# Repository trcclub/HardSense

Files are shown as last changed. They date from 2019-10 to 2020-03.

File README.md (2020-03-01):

# HardSense
Monitor local system sensors and display that data on a remote 2.8" LCD screen.
Full touch screen enabled.
Multiple screens including GPU details, CPU details

https://youtu.be/yXnQ3QwIAQI

The hardware monitoring is provided by the Open Hardware Monitor library:  https://github.com/openhardwaremonitor/openhardwaremonitor

NOTE:
To buld HardSenseESP, you need to change the partition scheme.

HardSenseESP Tools configuration settings:
	Board:  "ESP32 Dev Module"
	Partition Scheme: "HardSense ESP Partition"

In Arduino IDE, these are under the 'Tools' menu item.
In vMicro (Visual Micro for Visual Studio), they are under 'vMicro' menu item.

Essential bits: 
Bodmers TFT_ESPI:  https://github.com/Bodmer/TFT_eSPI

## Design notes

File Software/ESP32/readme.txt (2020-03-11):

AddItemToDisplayQueue(DisplayCommands::UpdateValue, String <payload>);
payload = "<key>,<value>"

Value (when needed) must be at least 3 characters long.
This means to have an empty value, you must use a space.
examples:
AddItemToDisplayQueue(DisplayCommands::UpdateValue, String ("a, "));
AddItemToDisplayQueue(DisplayCommands::UpdateValue, String ("a,12.3"));
AddItemToDisplayQueue(DisplayCommands::UpdateValue, String ("a,Hello"));

These will fail:
AddItemToDisplayQueue(DisplayCommands::UpdateValue, String ("a,"));
AddItemToDisplayQueue(DisplayCommands::UpdateValue, String ("a"));

Custom Partition for HardSenseESP

Default direcectory for existing partisions is:
(Windows):
C:\Users\<USERID>\AppData\Local\Arduino15\packages\esp32\hardware\esp32\1.0.4\tools\partitions

New partion file is called:
hardsense_esp_partition.csv

'hardsense_esp_partition.csv' is based on the file 'min_spiffs.csv' which can be found
in the default partitions directory.  This file is a good starting point when creating
a custom project. 

The file 'boards.txt' is also important:
C:\Users\<USERID>\AppData\Local\Arduino15\packages\esp32\hardware\esp32\1.0.4\boads.txt

esp32.menu.PartitionScheme.hardsenseESP=HardSense ESP Partition (1.9MB APP with OTA/190KB SPIFFS)
esp32.menu.PartitionScheme.hardsenseESP.build.partitions=hardsense_esp_partition
esp32.menu.PartitionScheme.hardsenseESP.upload.maximum_size=1966080

Copy the file 'hardsense_esp_partition.csv' to your partitions directory.
Add the 3 'esp32.menu.' lines above to your boards.txt file.
Restart arduino.
Select 'HardSense ESP Partition' from the tools or board config  menus.

Reference links:
https://robotzero.one/arduino-ide-partitions/
https://lastminuteengineers.com/esp32-ota-updates-arduino-ide/

Sketch uses 1511122 bytes (76%) of program storage space. Maximum is 1966080 bytes.

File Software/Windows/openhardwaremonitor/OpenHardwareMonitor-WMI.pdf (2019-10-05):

Page 1
The Open Hardware Monitor WMI Provider | Protected under copyright, Release 1 - 2010-10-18

# Open Hardware Monitor

### 1 Preface and document conventions

This documented is intended for those who wish to utilise the information exposed to WMI by the Open Hardware Monitor. Its intentions are to provide some basic understanding of some of the structures used, mainly those which are relatively obscure.

### 2 Type definitions

### 2.1 HardwareType

public enum HardwareType { Mainboard,
SuperIO,
CPU,
GpuNvidia,
GpuAti,
TBalancer,
Heatmaster,
HDD,
}

HardwareType is an enumeration intended to distinguish various piece of hardware from each other. One cannot rely on a specific type to indicate the presence of specific sensors, if any at all. This is merely an indication of hardware type in order to be able to potentially use different styles based upon the hardware type. The individual values will not be detailed in this matter, because the names themselves are very clear, and as said, hold no further meaning.

Page 2

### 2.2 SensorType

public enum SensorType {
Voltage,
Clock,
Temperature,
Load,
Fan,
Flow,
Control,
Level
}

SensorType is an enumeration to distinguish between various sensors. From a sensor’s type, one should derive which display format is to be used, as each type of sensor has a logical unit attached.

Sensor Type | Unit used | Recommended display format
Voltage | Volt | «value» V
Clock | Megahertz | «value» MHz
Temperature | Celsius | «value» °C
Load | Percentage | «value»%
Fan | Revolutions per minute | «value» RPM
Flow | Liters per hour | «value» L/h
Control | Percentage | «value»%
Level | Percentage | «value»%

A few of these types require extra attention, as they are intended to be used under very specific circumstances.

The Load, Control, and Level types each use percentages as their unit, but have distinctly different purposes.

- Load: Represents the load on a piece of hardware, where 100% represents a fully loaded component.
- Control: Typically used in conjunction with fan controllers, used to represent the duty cycle.
- Level: This is a generic % based level measure, used when the above both don’t apply.

The flow type is currently only used in conjunction with the Alphacool Heatmaster (http://www.alphacool.com/product_info.php/info/p674_Alphacool-Heatmaster.html) and mCubed’s T-Balancer bigNG. (http://www.t-balancer.com/english/bng.htm) These two fan controllers have flow sensors for those who have liquid cooled systems and wish to monitor the volumetric flow rate through the system.

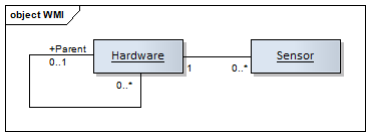
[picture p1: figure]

Page 3

### 3 The WMI provider

### 3.1 Basics

The Open Hardware Monitor publishes two distinct WMI classes, as detailed below. The namespace they are published to is called “root/OpenHardwareMonitor”. The cardinality between the 2 classes is defined as follows:

That is: Each sensor instance has exactly one matching parent hardware instance, but a hardware instance does not necessarily have any sensor instances attached to it.

Hardware may have a maximum of one matching parent hardware instance, but a hardware instance does not necessarily have any subhardware instances.

### 3.2 Hardware

Value type | Name | Description | Example
string | Name | Typically a combination of make and model | Intel Core 2 Duo E8400
string | Identifier | A unique identifier for this piece of hardware | /intelcpu/0
string | HardwareType | The HardwareType as defined in chapter 2.1 | CPU
string | Parent | The identifier of its parent Hardware; if any. | “/mainboard” or “”

The identifier includes a zero-based index in order to distinguish between identical pieces of hardware in a single system. This is common in multi-CPU and multi-GPU setups.

The parent identifier will be an empty string if there is no parent (as there won’t be for /mainboard for example).

The identifiers are unique per instance, but do not guarantee that the underlying hardware is 100% identical to a previous session. Taking the example of the Intel CPU above, a user could exchange this Intel Core 2 Duo E8400 for an Intel Core 2 Quad Q6600. The identifier will still be /intelcpu/0, but the underlying hardware has changed dramatically. Identifiers intend to identify a specific type of hardware, not the make and model. One has to take this into consideration when working with them, in order to avoid unexpected behaviour.

Page 4

### 3.3 Sensor

Value type | Name | Description | Example
string | Name | Typically relative to its parent | CPU Core #2
string | Identifier | A unique identifier for this Sensor | /intelcpu/0/load/1
string | SensorType | The SensorType as defined in chapter 2.2 | Load
string | Parent | The identifier of its parent Hardware | /intelcpu/0
float | Value | Last read value | 50
float | Min | Lowest read value | 0
float | Max | Highest read value | 100
int | Index | Index within the array of sensors of the same type | 1

The identifier includes a zero-based index in order to distinguish between similar sensors associated with a single piece of hardware. This is common in multi-core CPUs for examples, where each core can have its own Load or Temperature sensor.

The identifiers are unique per instance, but do not guarantee that the underlying hardware is 100% identical to a previous session. Taking the example of the Intel CPU above, a user could exchange this Intel Core 2 Duo E8400 for an Intel Core 2 Quad Q6600. The underlying hardware has changed dramatically, but where there were only 2 Load sensors before, there now are 4. Identifiers intend to identify a specific type of hardware, not the make and model. One has to take this into consideration when working with them, in order to avoid unexpected behaviour.

One has to take extra care with the Min, Max and Value properties. These are all of the float type, and as such will have to be parsed by the client before one can use them for calculations. One also has to take the unit associated with the SensorType into consideration.

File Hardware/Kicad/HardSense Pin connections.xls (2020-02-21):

TFT_Display |  | ESP32S | RTC | ESP32S
Touch | T_IRQ | N/A | DS | N/A
 | T_OUT | D19 | SCL | D22
 | T_IN | D23 | SDA | D21
 | T_CS | D15 | VCC | 3.3 v
 | T_CLK | D18 | GND | Gnd
TFT | MISO | D19
 | LED | 3.3v | Encoder | ESP32S
 | SCK | D18 | CLK | D35
 | MOSI | D23 | DT | D34
 | D/C | D4 | SW | N/A
 | Reset | D2 | + | 3.3 v
 | CS | D5 | GND | Gnd
 | GND | Gnd
 | VCC | 3/3 v | Button | ESP32S
 |  |  | Pin 1 | GND
 |  |  | Pin 2 | D13

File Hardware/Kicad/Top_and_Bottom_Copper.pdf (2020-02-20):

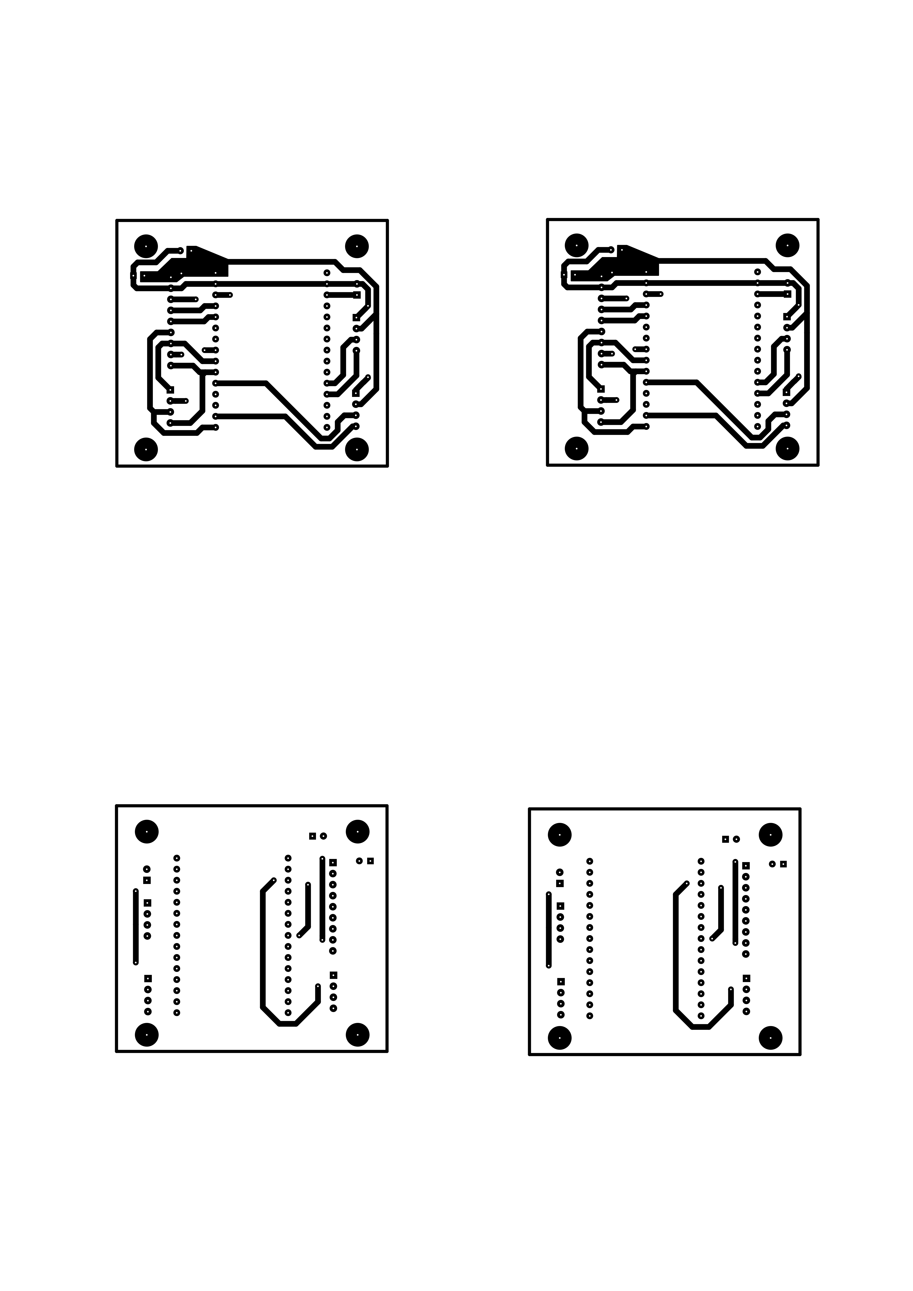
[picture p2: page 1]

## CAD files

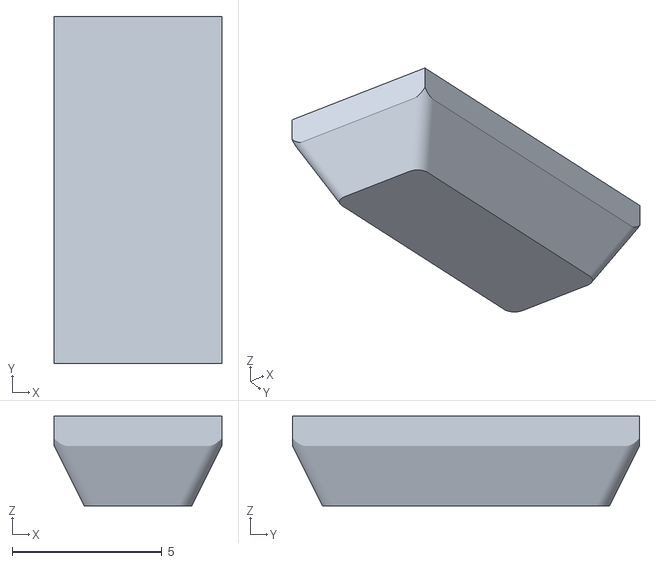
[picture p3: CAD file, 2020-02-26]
Hardware/STL Files/Foot Pad.stl
5.60 x 11.6 x 3.00

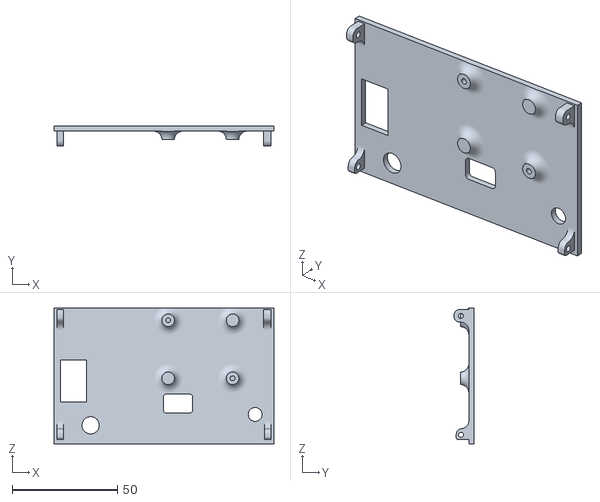
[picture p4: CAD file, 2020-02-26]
Hardware/STL Files/Back Plate.stl
104.6 x 9.40 x 64.5

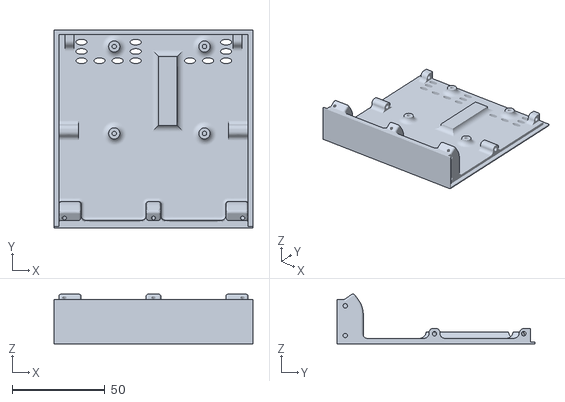
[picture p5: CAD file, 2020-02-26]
Hardware/STL Files/Base.stl
107.0 x 106.6 x 26.8

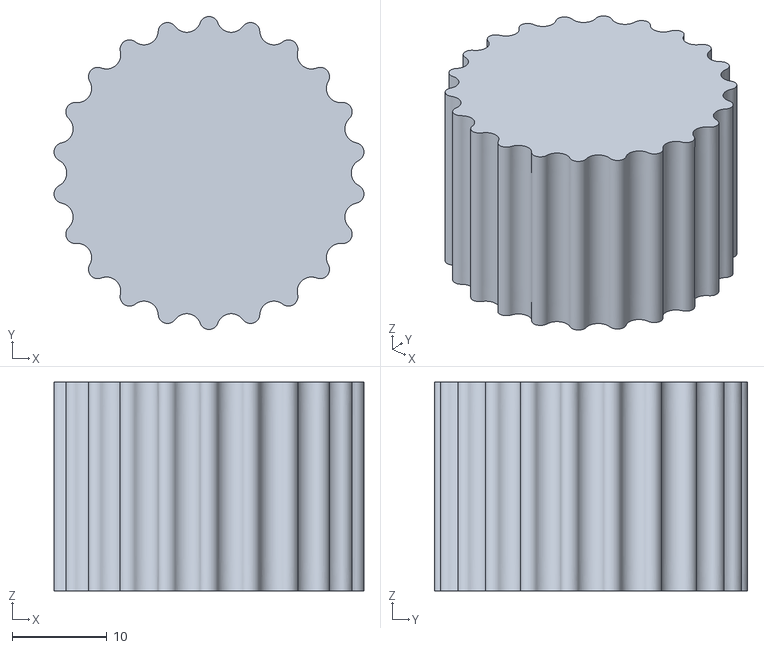
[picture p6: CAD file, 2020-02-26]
Hardware/STL Files/Metric Barrell.stl
32.7 x 33.0 x 22.0

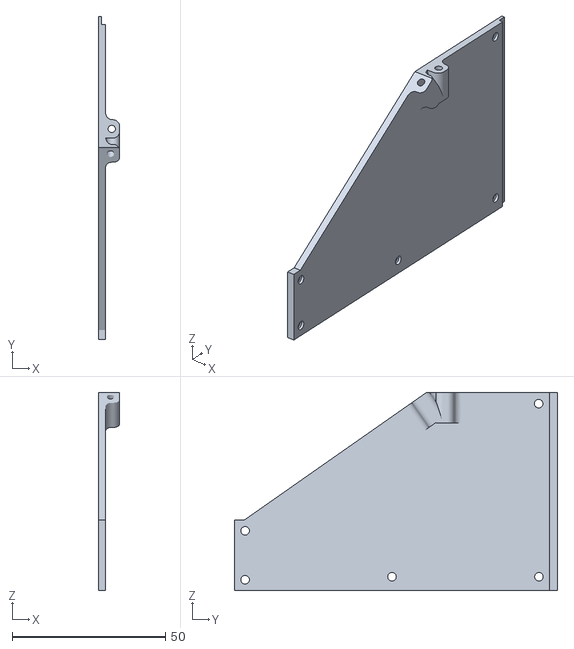
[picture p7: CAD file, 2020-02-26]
Hardware/STL Files/Left Side Panel.stl
7.00 x 105.6 x 64.7

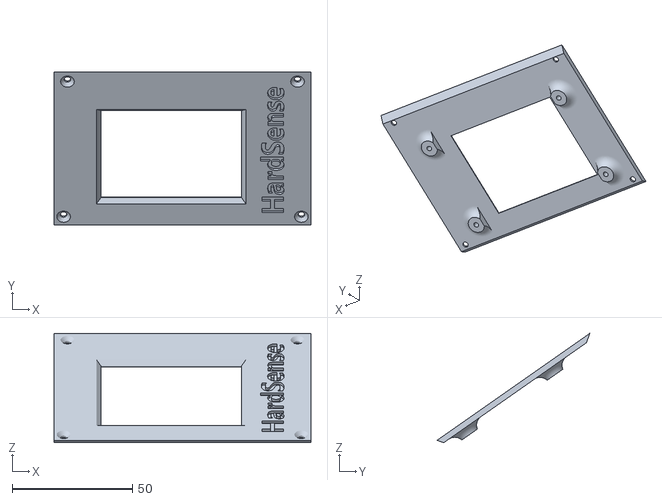
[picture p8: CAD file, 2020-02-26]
Hardware/STL Files/Display Panel.stl
107.0 x 63.6 x 45.6

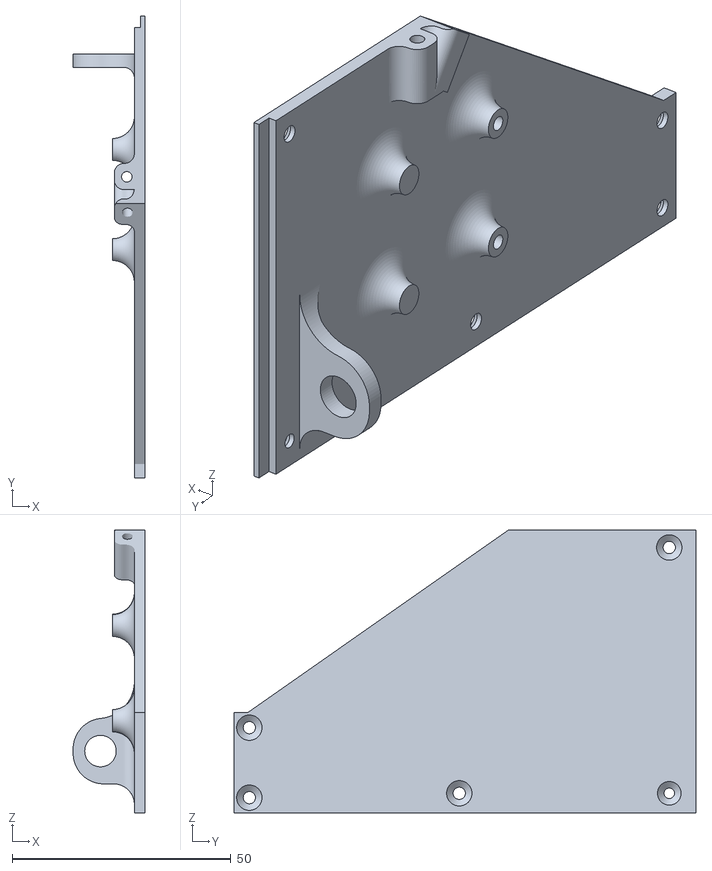
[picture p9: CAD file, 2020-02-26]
Hardware/STL Files/Right Side Panel.stl
16.4 x 105.6 x 64.7

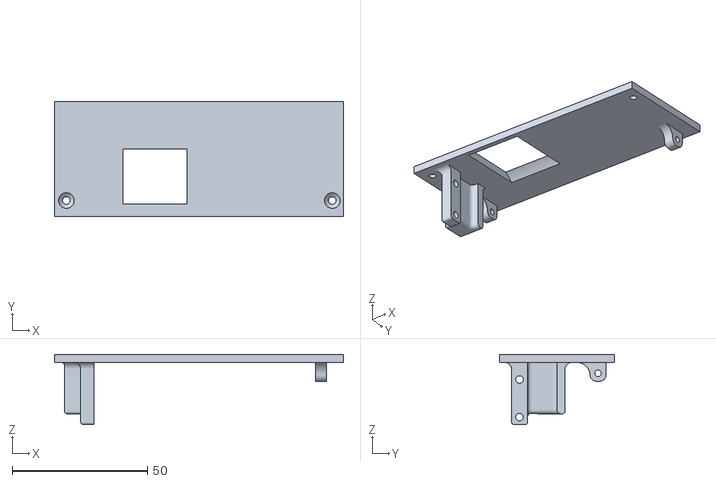
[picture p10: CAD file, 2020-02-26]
Hardware/STL Files/Top Plate.stl
107.0 x 42.8 x 26.0

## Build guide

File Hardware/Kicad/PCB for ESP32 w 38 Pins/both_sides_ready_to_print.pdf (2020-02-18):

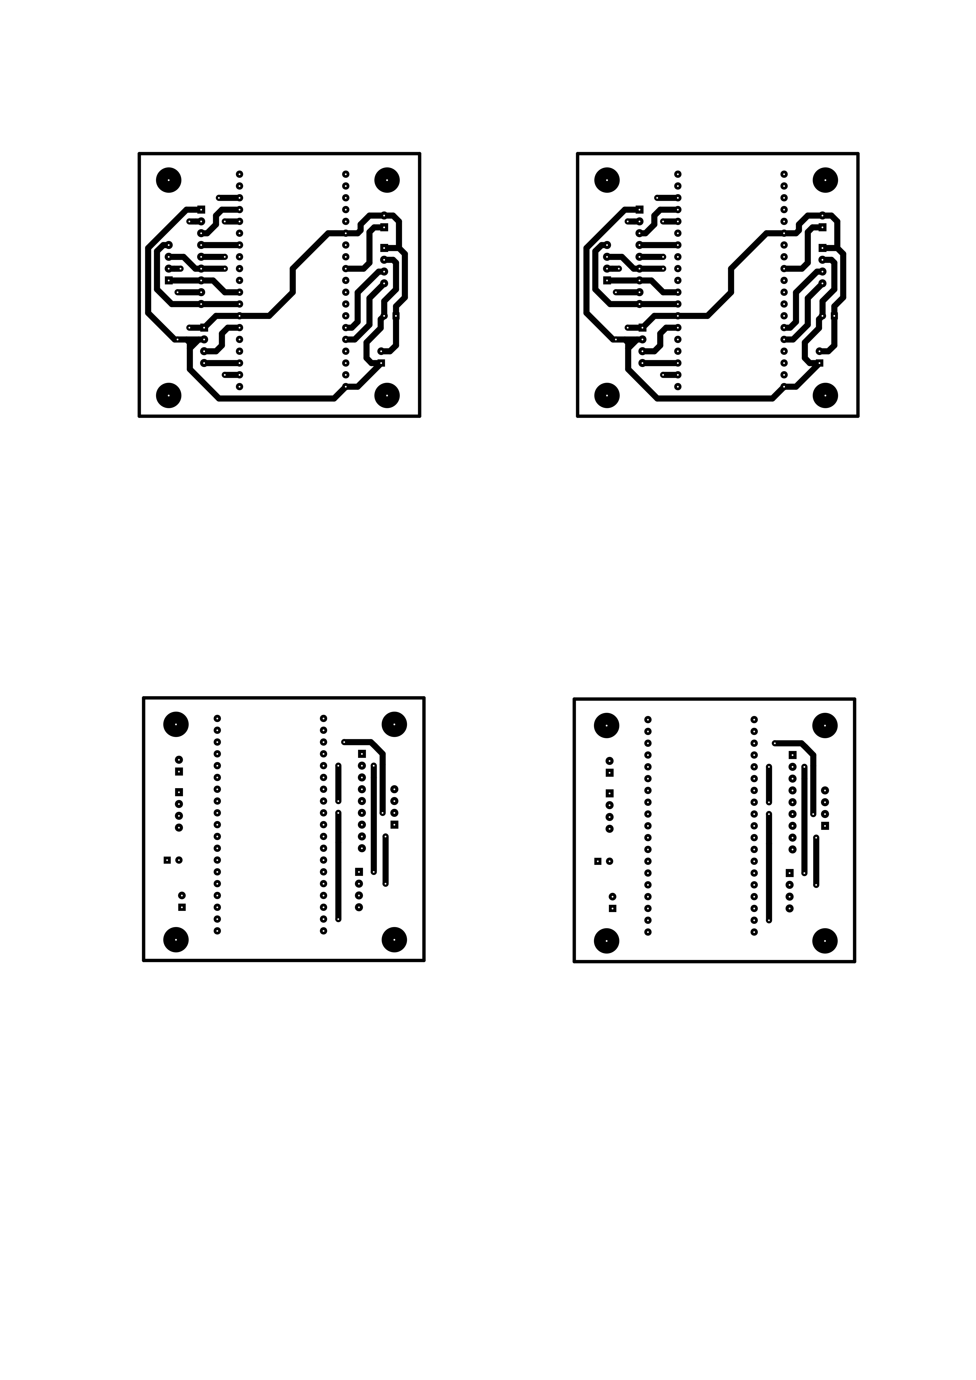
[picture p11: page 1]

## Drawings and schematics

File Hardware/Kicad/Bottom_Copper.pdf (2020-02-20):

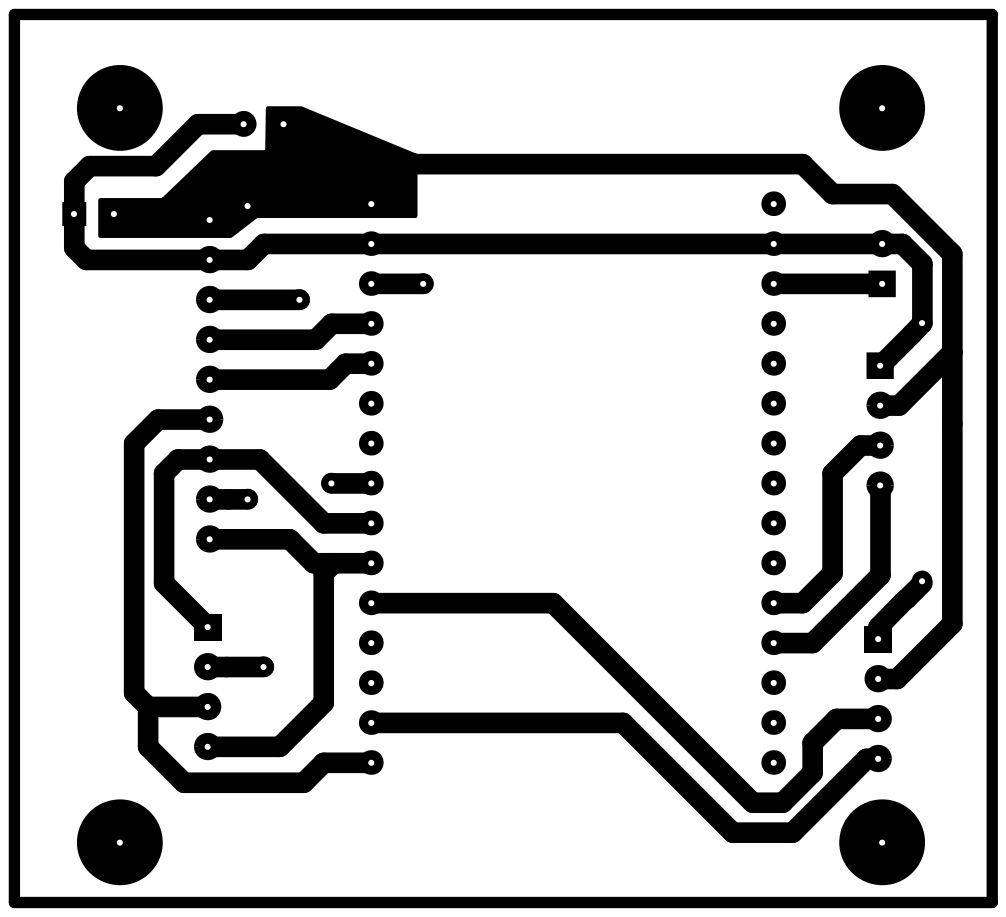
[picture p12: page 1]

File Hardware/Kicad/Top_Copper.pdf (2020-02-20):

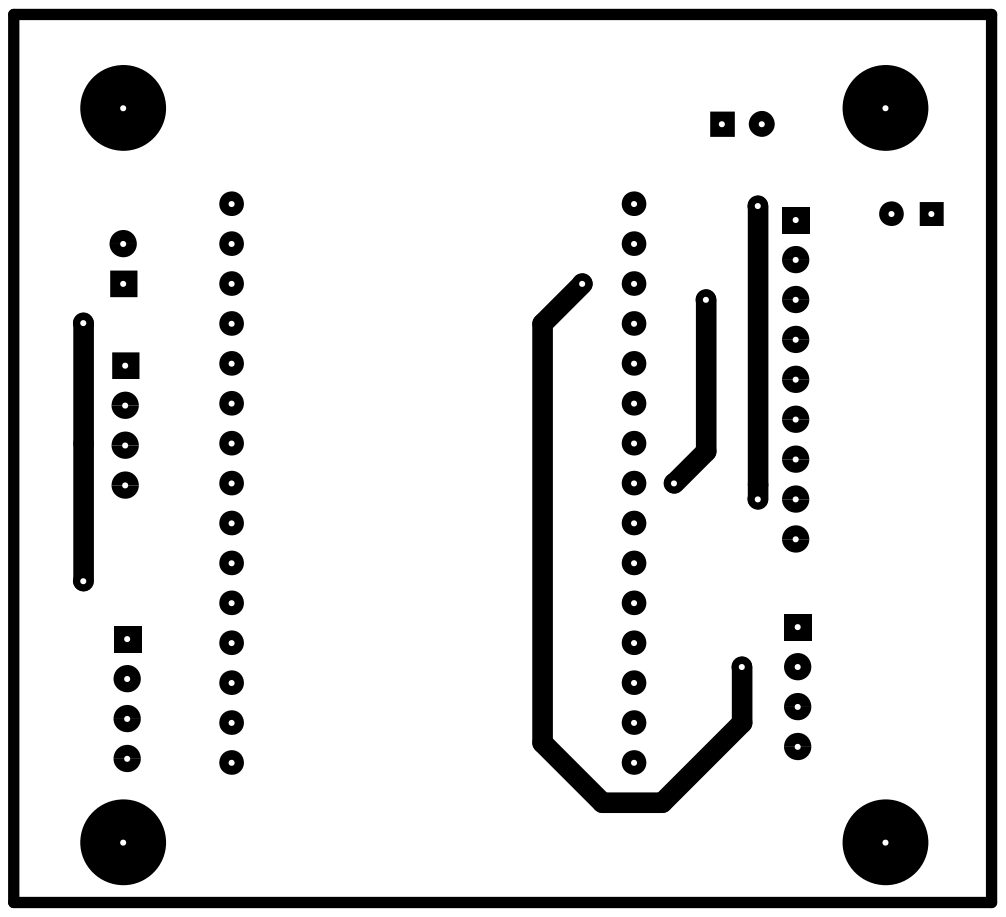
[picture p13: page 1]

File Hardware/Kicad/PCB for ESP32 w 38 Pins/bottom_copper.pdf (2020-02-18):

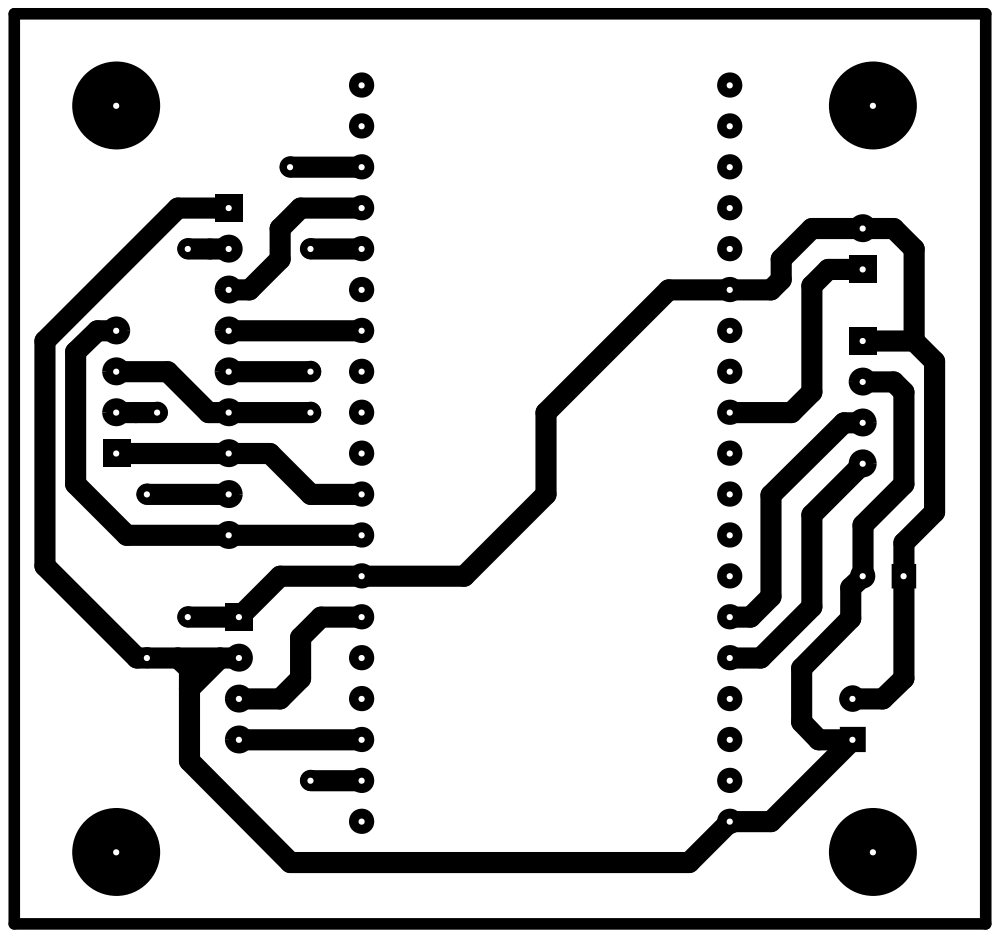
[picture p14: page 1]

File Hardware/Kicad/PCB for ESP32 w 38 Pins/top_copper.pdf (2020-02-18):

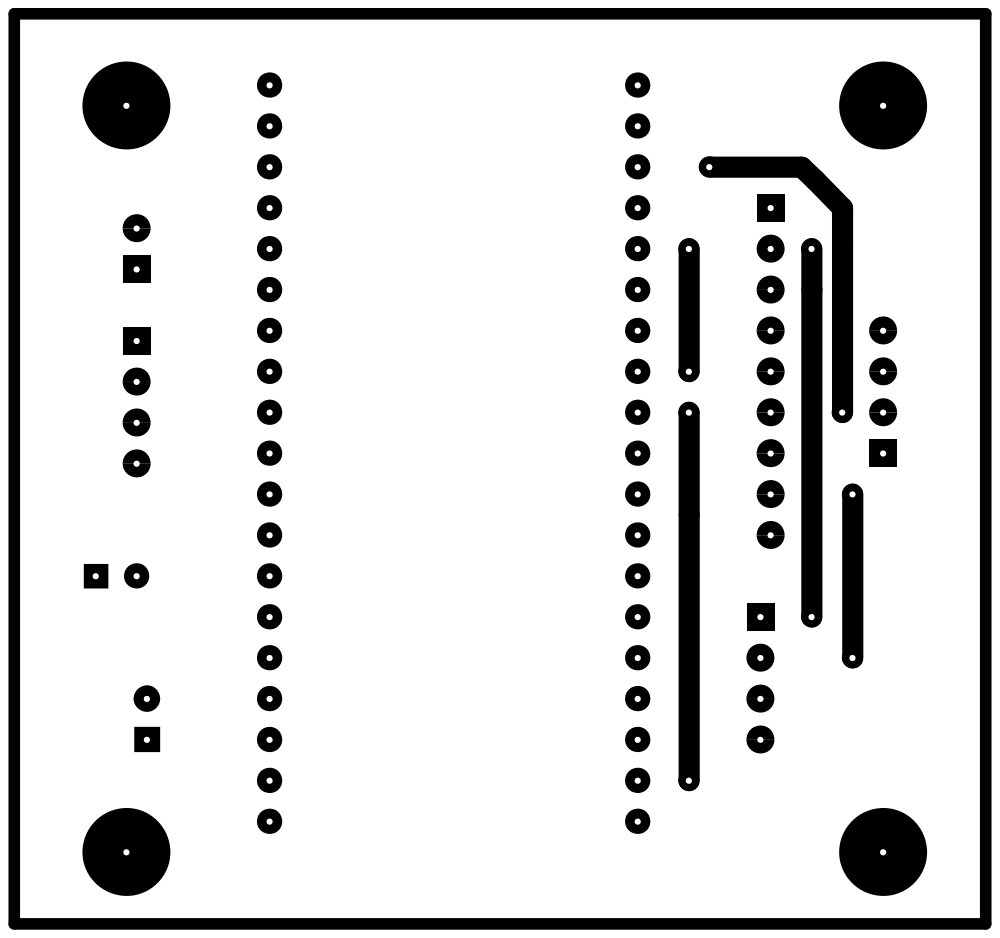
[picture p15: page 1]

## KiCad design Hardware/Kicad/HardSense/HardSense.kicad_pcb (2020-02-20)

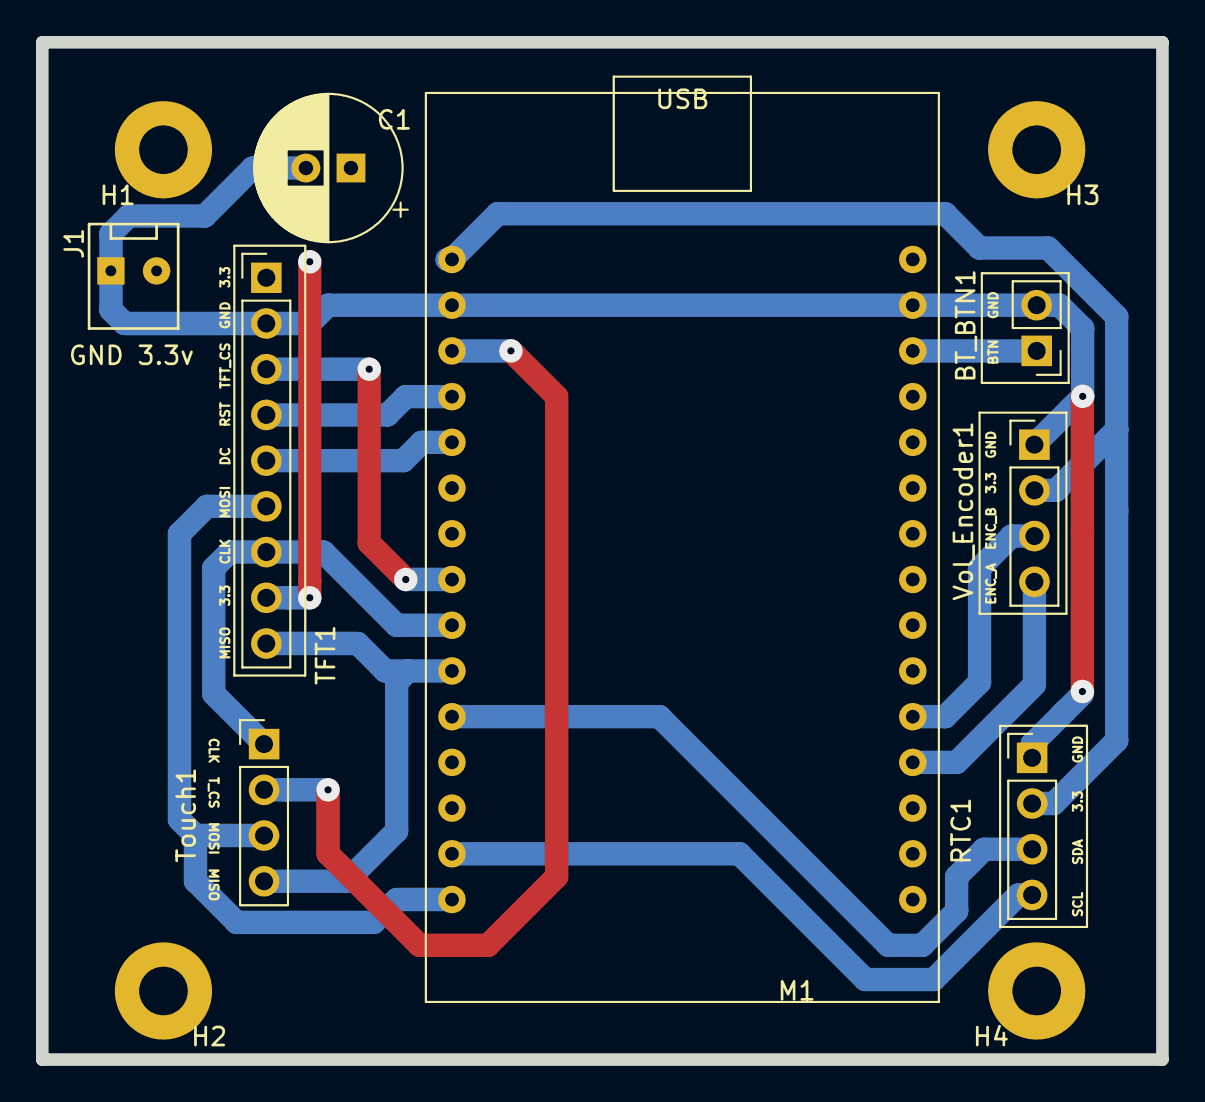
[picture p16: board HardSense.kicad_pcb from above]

Board: 2 copper layers, 62.2 x 56.5 mm, 12 parts (0 on the bottom side), 14 nets.

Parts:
BT_BTN1: Conn_01x02; PinHeader_1x02_P2.54mm_Vertical
C1: 100uF; CP_Radial_D8.0mm_P2.50mm
H1, H2, H3, H4: MountingHole; MountingHole_2.7mm_Pad
J1: Conn_01x02; PinHeader_1x02_P2.54_Friction_Lock
M1: ESP32_DevKitC-30Pin; ESP32S_30Pin
RTC1: Conn_01x04; PinHeader_1x04_P2.54mm_Vertical
TFT1: Conn_01x09; PinHeader_1x09_P2.54mm_Vertical
Touch1: Conn_01x04; PinHeader_1x04_P2.54mm_Vertical
Vol_Encoder1: Conn_01x04; PinHeader_1x04_P2.54mm_Vertical

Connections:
3.3V: C1.1, J1.2, M1.1, RTC1.2, TFT1.1, TFT1.8, Vol_Encoder1.2
/BT_BTN: BT_BTN1.1, M1.28
/ENC_A: M1.19, Vol_Encoder1.4
/ENC_B: M1.20, Vol_Encoder1.3
/SCL: M1.14, RTC1.4
/SDA: M1.11, RTC1.3
/SPI_CLK: M1.9, TFT1.7, Touch1.1
/SPI_MISO: M1.10, TFT1.9, Touch1.4
/SPI_MOSI: M1.15, TFT1.6, Touch1.3
/TFT_CS: M1.8, TFT1.3
/TFT_DC: M1.5, TFT1.5
/TFT_RST: M1.4, TFT1.4
/T_CS: M1.3, Touch1.2
GND: BT_BTN1.2, C1.2, J1.1, M1.2, M1.29, RTC1.1, TFT1.2, Vol_Encoder1.1

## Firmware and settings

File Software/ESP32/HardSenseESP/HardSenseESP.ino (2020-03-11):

/*                                                                                                                                                                  
 Name:		HardSenseESP.ino
 Created:	10/7/2019 7:07:38 AM
 Author:	Kitecraft
*/
#include <ESP32Encoder.h>
#include "src/DisplayHandler/DisplayHandler.h"
#include "src/HSSerial/HSSerial.h"
#include "src/QueueItem.h"
#include "src/GlobalDefinitions.h"

TaskHandle_t Display_Core_Task_Handle;

DisplayHandler displayHandler;
HSSerial hsSerial;
Queues allQueues;

const byte btButton = 13;
ESP32Encoder volumeEncoder;
const byte encoderA_pin = 35;
const byte encoderB_pin = 34;
volatile int32_t volumeLevel = 0;

hw_timer_t* heartbeatTimer = NULL;
void IRAM_ATTR onTimer()
{
  hsSerial.FireHeartbeat();
}

void setup() {
	Serial.begin(115200);

	displayHandler.Init(&allQueues);

	// Init the bluetooth button
	pinMode(btButton, INPUT_PULLUP);

	heartbeatTimer = timerBegin(0, 80, true);
	timerAttachInterrupt(heartbeatTimer, &onTimer, true);
	timerAlarmWrite(heartbeatTimer, HEARTBEAT_TIMER_POLL_TIME, true);
		
	xTaskCreatePinnedToCore(
		TFT_Core_Proc,                  /* pvTaskCode */
		"DisplayHandler",            /* pcName */
		3000,                   /* usStackDepth */
		NULL,                   /* pvParameters */
		1,                      /* uxPriority */
		&Display_Core_Task_Handle,                 /* pxCreatedTask */
		0);

	if (!hsSerial.Init(&allQueues, HeartbeatTimerEnabled))
	{
		Serial.println("Failed to init SPIFFS");
		while (true) {
			delay(100);  // Spin because we can't go any further without SPIFFS
		}
	}

	volumeEncoder.attachHalfQuad(encoderA_pin, encoderB_pin);
	volumeEncoder.clearCount();
	
	if(IsBTButtonPressed())
	{
		allQueues.AddItemToDisplayQueue(DisplayCommands::ChangeScreen, String(ScreenTypes::BluetoothConfigurator));
		hsSerial.HandleConfigurator();
	}
	allQueues.AddItemToDisplayQueue(DisplayCommands::ChangeScreen, String(ScreenTypes::SplashScreen));
}


void loop() 
{
	if (!hsSerial.connectedToSomething) {
		hsSerial.ConnectToHardsenseServer();
	}
	
	hsSerial.HandleInput();
	HandleVolumeEncoder();
	yield();
	
	while (!allQueues.outputQueue.isEmpty())
	{
		portENTER_CRITICAL(&allQueues.outputQueueMux);
		QUEUE_ITEM currItem = allQueues.outputQueue.dequeue();
		portEXIT_CRITICAL(&allQueues.outputQueueMux);

		hsSerial.AddStringToOutputMessage(TRANS__KEY(currItem.key), currItem.value);
	}
	hsSerial.HandleOutput();

	yield();
}

void TFT_Core_Proc(void* parameter)
{
	displayHandler.Run();
}

bool IsBTButtonPressed()
{
	if (!digitalRead(btButton))
	{
		return true;
	}
	return false;
}

void HandleVolumeEncoder()
{
	uint32_t currValue = volumeEncoder.getCount();
	if (currValue != volumeLevel)
	{
		if (currValue > volumeLevel)
		{
			allQueues.AddItemToOutputQueue(TRANS__KEY::INCREASE_VOLUME, "");
		}
		else 
		{
			allQueues.AddItemToOutputQueue(TRANS__KEY::DECREASE_VOLUME, "");
		}
		volumeLevel = currValue;
	}
}

void HeartbeatTimerEnabled(bool enabled)
{
	if (enabled)
	{
		timerAlarmEnable(heartbeatTimer);

	}
	else
	{
		timerAlarmDisable(heartbeatTimer);
	}
}

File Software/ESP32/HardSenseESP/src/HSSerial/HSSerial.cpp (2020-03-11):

#include "HSSerial.h"
#include "../DisplayHandler/DisplayHandler.h"
#include <RTClib.h>
#include <ESPmDNS.h>
#include <WiFiUdp.h>
#include <ArduinoOTA.h>

HSSerial::HSSerial()
{
	connectedToSomething = false;
	OTA_Enabled = false;
	OTA_Initialized = false;
	OTA_Completion_Percentage = 0;
	ConnectedToWifi = false;
	wifiSerial = NULL;
	btSerial = NULL;
	heartbeatCounter = 0;
	heartbeatMux = portMUX_INITIALIZER_UNLOCKED;
}

HSSerial::~HSSerial()
{
	if (wifiSerial != NULL)
	{
		delete(wifiSerial);
	}
	if (btSerial != NULL)
	{
		delete(btSerial);
	}
}

bool HSSerial::Init(Queues *newQueues, void(*HeartbeatTimerEnabled_Func)(bool))
{
	HeartbeatTimerEnabled = HeartbeatTimerEnabled_Func;
	allQueues = newQueues;
	allQueues->outputQueueMux = portMUX_INITIALIZER_UNLOCKED;

	HSFileSystem hsFS;
	if (!hsFS.init()) {
		Serial.println("Failed to init SPIFFS");
		return false;
	}
	
	if (!hsFS.getSettings(hardsenseSettings))
	{
		Serial.println("Failed to retrieve settings from SPIFFS!");
		return false;
	}
	
	return true;
}

bool HSSerial::IsPasswordSet()
{
	if (strcmp(hardsenseSettings.password,"") == 0)
	{
		return false;
	}
	return true;
}

bool HSSerial::UpdateSetting(char key, String value)
{
	switch (key) {
	case TRANS__KEY::CONFIG_SET_SSID:
		value.toCharArray(hardsenseSettings.ssid, FIELD_MAX_LENGTH);
		break;
	case TRANS__KEY::CONFIG_SET_PASSWORD:
		value.toCharArray(hardsenseSettings.password, FIELD_MAX_LENGTH);
		break;
	case TRANS__KEY::CONFIG_SET_SERVER_HOSTNAME:
		value.toCharArray(hardsenseSettings.serverName, FIELD_MAX_LENGTH);
		break;
	case TRANS__KEY::CONFIG_SET_SERVER_PORT:
		hardsenseSettings.serverPort = value.toInt();
		break;
	case TRANS__KEY::CONFIG_SET_WIFI_DEVICED_ID:
		value.toCharArray(hardsenseSettings.wifiDID, FIELD_MAX_LENGTH);
		break;
	case TRANS__KEY::CONFIG_SET_BT_DEVICE_ID:
		value.toCharArray(hardsenseSettings.btDID, FIELD_MAX_LENGTH);
		break;
	default:
		return false;
	}
	return SaveSettingsToFS();
}

bool HSSerial::SaveSettingsToFS()
{
	HSFileSystem hsFS;
	if (!hsFS.init()) {
		Serial.println("Failed to init SPIFFS");
		return false;
	}

	if (!hsFS.writeSettings(hardsenseSettings))
	{
		Serial.println("Failed to write settings to SPIFFS!");
		return false;
	}

	UpdateBluetoothDisplay();
	return true;
}

void HSSerial::UpdateBluetoothDisplay()
{
	allQueues->AddItemToDisplayQueue(DisplayCommands::UpdateValue, String("a," + String(hardsenseSettings.ssid)));

	String value = "b,";
	if(IsPasswordSet())
	{
		value += "******";
	} else {
		value += " ";
	}

	allQueues->AddItemToDisplayQueue(DisplayCommands::UpdateValue, value);
	allQueues->AddItemToDisplayQueue(DisplayCommands::UpdateValue, String("c," + String(hardsenseSettings.serverName)));
	allQueues->AddItemToDisplayQueue(DisplayCommands::UpdateValue, String("d," + String(hardsenseSettings.serverPort)));
	allQueues->AddItemToDisplayQueue(DisplayCommands::UpdateValue, String("e," + String(hardsenseSettings.wifiDID)));
	allQueues->AddItemToDisplayQueue(DisplayCommands::UpdateValue, String("f," + String(hardsenseSettings.btDID)));
}

void HSSerial::Enable_OTA()
{
	allQueues->AddItemToDisplayQueue(DisplayCommands::UpdateValue,String("a," + String(hardsenseSettings.ssid)));

	WiFi.mode(WIFI_STA);
	WiFi.setHostname(hardsenseSettings.wifiDID);
	WiFi.begin(hardsenseSettings.ssid, hardsenseSettings.password);

	while (WiFi.waitForConnectResult() != WL_CONNECTED) {
		Serial.println("Connection Failed! ...");
		delay(5000);
	}

	if (!WiFi.isConnected()) {
		return;
	}

	// Send notfication of successfull WiFi connection
	allQueues->AddItemToDisplayQueue(DisplayCommands::UpdateValue,String("b," + String(hardsenseSettings.ssid)));
	
	ArduinoOTA.setHostname(hardsenseSettings.wifiDID);
	ArduinoOTA
	.onStart([this]() {		
		String type;
		if (ArduinoOTA.getCommand() == U_FLASH)
		{
			type = "sketch";
		}
		else // U_SPIFFS
		{
			type = "filesystem";
		}
		
		// NOTE: if updating SPIFFS this would be the place to unmount SPIFFS using SPIFFS.end()
		allQueues->AddItemToDisplayQueue(DisplayCommands::UpdateValue,String("c, "));
	})
	
	.onEnd([this]() {
		allQueues->AddItemToDisplayQueue(DisplayCommands::UpdateValue,String("e, "));
	})

	.onProgress([this](unsigned int progress, unsigned int total) {
		int percentage  = progress / (total / 100);
		if(percentage != OTA_Completion_Percentage)
		{
			allQueues->AddItemToDisplayQueue(DisplayCommands::UpdateValue,String("d," + String(percentage)));
			OTA_Completion_Percentage = percentage;
		}
	})

	.onError([](ota_error_t error) {
		Serial.printf("Error[%u]: ", error);
		if (error == OTA_AUTH_ERROR) Serial.println("Auth Failed");
		else if (error == OTA_BEGIN_ERROR) Serial.println("Begin Failed");
		else if (error == OTA_CONNECT_ERROR) Serial.println("Connect Failed");
		else if (error == OTA_RECEIVE_ERROR) Serial.println("Receive Failed");
		else if (error == OTA_END_ERROR) Serial.println("End Failed");
	});

	ArduinoOTA.begin();
	OTA_Initialized = true;
}

void HSSerial::HandleConfigurator()
{
	while(true)
	{
		if(OTA_Enabled)
		{
			if(!OTA_Initialized)
			{
				Enable_OTA();
			}
			ArduinoOTA.handle();
			HandleCommandQueue();
		}
		else 
		{
			HandleBluetooth();
		}
		yield();
	}
}

void HSSerial::HandleBluetooth()
{	
	connectedToSomething = false;

	btSerial = new BluetoothSerial();
	InputAvailable = &HSSerial::BT_Available;
	ReadInputByte = &HSSerial::BT_Read;;
	ReadInputStringUntil = &HSSerial::BT_ReadStringUntil;
	PrintMessageToOutput = &HSSerial::BT_PrintChar;

	btSerial->setTimeout(50);
	btSerial->begin(String(hardsenseSettings.btDID));

	while (!OTA_Enabled)
	{
		WaitForBTConnection();
		while (connectedToSomething && !OTA_Enabled)
		{
			WorkhorseFunction();
			yield();
		}
	}
	btSerial->end();
	btSerial->disconnect();
}

bool HSSerial::WaitForBTConnection()
{
	while (!connectedToSomething && !OTA_Enabled)
	{
		WorkhorseFunction();
		if (connectedToSomething)
		{
			break;
		}
		yield();
	}
}

void HSSerial::WorkhorseFunction()
{
	HandleInput();
	HandleOutput();
	HandleCommandQueue();
}

void HSSerial::HandleCommandQueue()
{
	while (!allQueues->commandQueue.isEmpty())
	{
		portENTER_CRITICAL(&allQueues->commandQueueMux);
		QUEUE_ITEM currItem = allQueues->commandQueue.dequeue();
		portEXIT_CRITICAL(&allQueues->commandQueueMux);

		switch (currItem.key) {
		case HardSense_Commands::BeginOTA:
			OTA_Enabled = true;
			break;
		case HardSense_Commands::RefreshBluetoothDisplay:
			UpdateBluetoothDisplay();
			break;
		case HardSense_Commands::DeleteTouchcalibration:
			SPIFFS.remove(CALIBRATION_FILE);
			allQueues->AddItemToDisplayQueue(DisplayCommands::ChangeScreen,String(ScreenTypes::BluetoothConfigurator));
			break;
		default:
			break;
		}
		yield();
	}
}
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

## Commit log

2019-10-05 Added hardware and senor ignore lists however I'm unhappy with how the sensor ignore list is being passed around to sub objects and what-not. Need to refactor. Also added the beginnings of the thread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
2019-10-05 Adding my modified version of the openhardwaremonitor. I've added a new value the SensorType enum for 'BPS' This is to handle the 'Bytes Per Second' value from the NIC Interfaces.
2019-10-05 The Memory Mapped File handler now writes and reads. All fields are maxlength of 10 and are of type double. Refactored the NetSpeedMonitor to be able to montior multiple items. Also change the new Se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
2019-10-06 Tightened up access around the MemoryMappedFile. Added mutexs around the mmvAccessor. Class should be thread safe now. I hope.
    Added a couple of settings for memory mapped file name and default field size. This way those are not hardcoded values.
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2019-10-07 Made the allAvailableSensors list in the HardwareMonitor static. This will allow the socket thread handlers to access the list of sensors without needing an object.
2019-10-07 Did some refactoring as I need to get the Hardware items Name into the senor item. This is really helpfull for knowing the HDD logical drive identifer (C:, G:, F:, ...) and which sensor is for which 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
2019-10-08 New DataStreamer class with threading. This now handles the read and writing to the socket and will also be where the memory mapped file is polled.
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2019-10-08 Fixed the DataStreamer threadproc method to join the existing threads instead of spinning on it's own thread.
2019-10-09 Added a heartbeat to the datastreamer. This way the server can disconnect and properly close the sockets if the client has stopped responding (disconnected)
2019-10-09 Committing the initial bits of the Bluetooth Configurator for both Windows and ESP32 projects. This is also the first code update to HardSenseESP! WooHoo! Progress is being acheived.
2019-10-11 An early working version of the Bluetooth configurator. Both Windows and ESP32
2019-10-12 I finally have a combination wifi socket and bluetooth serial handler with common interface.
2019-10-13 Fixed a bug for the Wifi read/write data. Updated to new format. Added beginnnig of socket data streaming.
    [HSSerial.cpp, HardSenseESP.ino]
2019-10-15 Added mutexes around accessing the Display and Output Queue objects. Also added mutex around the actual OutputData and changed the HandleOoutput a bit. Startd to add a heartbeat and a way to reconnec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
2019-10-15 I seem to have working heartbeat timers in both directions. And, HardSenseESP can now detect a dropped connection and re-connect automatically.
2019-10-16 Added new fonts. Small bit of refactoring including a bit more error handling.
    [HardSenseESP.ino, User_Setup.h]
2019-10-17 Some refactoring and trying to fix a bug. I've got one fixed. looking for more.
    [DisplayHandler.cpp, HSSerial.cpp, HS_HomeScreen.h]
2019-10-17 Ok, things seem to be working relativly well all though I still think there is a bug (maybe a memory leak or handle leak?) that is causing an occasional unhandled exception after HardSenseESP has bee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
    [HS_HomeScreen.h, HS_ScreenBase.cpp, HS_ScreenBase.h]
2019-10-18 Added some of the GPU Panel on the home screen. My idea about using classes and function pointers seems to be bearing fruit.
2019-10-18 Who knows what I"ve broken now. :(
    [DisplayHandler.cpp, HSSerial.cpp, HS_BluetoothConfiguratorScreen.h]
2019-10-18 stuff is broken all over
    [HS_HomeScreen.h]
2019-10-18 I change the Queue Item to use a String for the value instead of a Char[]. I'm hoping this helps with a problem where the ESP32 would blank the screen and stop responding. It's an odd problem that i 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
    [DisplayHandler.cpp, HSSerial.cpp, HS_BluetoothConfiguratorScreen.h]
2019-10-19 Started adding a second home screen where I can try out some things with sprites.
    But, more importantly, I curshed a few severe bugs. Memory leaks in the widget and screen classes. Must remember to always:
    Sprites:
    unloadFont & deleteSprite
    Every class destructor also needs to TFT->unloadFont() as well. At least for now until I figure this out more. But no more memory leaks!
    [DisplayHandler.cpp, HS_HomeScreen_B.h, HS_ScreenBase.cpp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]
2019-10-19 I'm relativly sure that I've fixed a bug or two now. The onTimer() was doing way to much work. Plush, the HSSerial function it calls also needed to be IRAM_ATTR
    Also started updating the home screen with the use of a sprite to update the text.
    [DisplayHandler.cpp, HSSerial.cpp, HS_HomeScreen.h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]
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2019-10-20 Fixed the DrawBoxWithBorderAndDropShadow() method to no longer draw the box 1 pixel too wide and too high. Refactored HSSerial a bit to use TRANS_KEY instead of char
    [HSSerial.cpp, HS_HomeScreen.h, HS_ScreenBase.cpp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]
2019-10-20 Manged to get the dials working again on the home screen. There seems to be a bug in TFT_eSpi where it is mishandling memory for a sprite.
    [HS_HomeScreen.h]
2019-10-20 Try to put some of the code back to where it was before that last push. I don't understand this really weird bug in TFT_eSpi.
    [HSSerial.cpp, SerialInterface.h]
2019-10-21 Forgot to update the lastUpdatTime var in the UpdateScreenOnInterval. Oops. Fixed!
    [HS_HomeScreen.h]
2019-10-23 I seem to have a working graph for GPU temperature and fan load. Have added it to the Game screen now.
2019-10-23 Fixed a bug in the GPU Memory Load display. Made sure all fields have a value at Draw time.
    [HS_GameScreen.cpp, HS_GameScreen.h]
2019-10-23 Fixed a couple bugs in the memPanel. Don't use transparent background when trying to overwrite an area. It just doesn't work eh.
    [HS_GameScreen.cpp, HS_GameScreen.h]
2019-10-24 Finally found the bug that was causing the Dial's to stop working and fixed it. Change the way the TFT is passed into widget class and used. It's now a pointer. Refactored the Screen drawbox func to 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
    [HS_GameScreen.cpp, HS_GameScreen.h, HS_ScreenBase.cpp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]
2019-10-26 Most of the game screen is complete. Fixed a couple bugs as well.
    [HS_GameScreen.cpp, HS_GameScreen.h]
2019-10-27 Increased the stack size of the DisplayHandler task. I finally caught one of the infrequent crashes in the serial monitor: "Stack smashing protect failure!".
    [HardSenseESP.ino]
2019-10-28 Tried to clean up the code a bit by removing seemingly unnecessary calls to yield(). Removed unusded font file. The screen has been running for quite a while on the Games screen now and has not gone 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
    [DisplayHandler.cpp, HSSerial.cpp, HardSenseESP.ino]
2019-10-30 Bit more refactoring in an effort to fix Issue #1 The calls to unloadfont from the TFT (screenbase) are not only superfluous, they may be doing something bad.
    [DisplayHandler.cpp, HS_ScreenBase.cpp, HardSenseESP.ino]
2019-10-30 Adding initial Kicad project for circuit boards.
    [HardSense.kicad_pcb, HardSense.sch]
2019-10-31 Add FPS counter Hardware item and Sensor to the list of available sensors. Next is to buld the FPS montior itself. Add a 'FPS' type to the SensorType. At least for now. I might change this to one of 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
2019-11-01 Fixed a couple bugs with how the time is set and read. Little bit of refactoring.
    [DisplayHandler.cpp, HSSerial.cpp, HS_HomeScreen.h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]
2019-11-05 Changed the number of frames used to calculate the FPS. It still isn't great, but it's not horrible.
2019-11-08 Checking this in. All sorts of things somehow went wrong with VisualMicro, Arduino, and ESP32 borads. I had to re-install eveything in order to fix it. I don't know what was wrong. HardSenseESP just 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
2019-11-20 Most of a working CPU Details screen.
    [HardSense.sch]
2019-11-27 Just a small change to help in debugging the screen blanking problem.
    [HSSerial.cpp]
2019-11-27 Added an encoder to HardSenseESP as well as code to send a VolumeUp and VolumeDown commands. Added ability to increase/decrease volume to HardSense.
2019-11-29 Fixed a bug where the amount of free system ram was ending up being used as the C: drive free space value (missed a break in the case statement)
2019-12-02 Add a couple of yeild() calls back. Since removing them, I started to see inexplicable crashes which seemed to point to clearing a counter in the task.
    [DisplayHandler.cpp, HSSerial.cpp]
2019-12-02 Ok, the error I was seeing was not from yeild() (it never is!), but is instead from the ESP32Encoder and comeing from 'pcnt_counter_clear'. Moving the clear() command to after the Attach... statement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
    [HardSenseESP.ino]
2019-12-02 Added a couple of yeilds() back into the DisplayHandler as I was starting to see watchdog timer errors. I've now been runing HardSenseESP for many hours without a single problem All seems well now. H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
    Also began to add the new SplashScreen, but I think I need to re-think how to do that. Sadness.
    [DisplayHandler.cpp, HSSerial.cpp, HardSenseESP.ino]
2019-12-10 Update the mainboard schematic and PCB.
    Added step file for the mainboard and a couple of jpeg images.
    [HardSense.kicad_pcb, HardSense.sch]
2020-02-06 Moved the btButton (BlueTooth button) to GPIO 37 to accommodate a better trace on the final PCB.
2020-02-13 Initial Commit for this branch. Need to fix the Bluetooth display screen.
    [HardSenseESP.ino]
2020-02-13 Fixed up the BlueTooth Display screen a bit. There's still an underlying bug on how the font is accessed after the hs_serial object takes the SPIFFS for itself and saves the settings. This seems to b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
    [DisplayHandler.cpp, HSSerial.cpp, HardSenseESP.ino]
2020-02-13 Added wifi and bluetooth device IDs to the hardsens.txt configuration file.
    Fixed bug in Displaying labels on the Bluetooth configurator screen.
    [HSFileSystem.cpp, HSSerial.cpp]
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2020-02-13 Added new ability to set the Wifi and Bluetooth device IDs via the BlueTooth Configuator. Includes new fields on the Bluetooth screen in HardSense64 New protocols keys New actions in the dispatchers
2020-02-14 Trying to undo the things I did in the last changes. I didn't realize I was still in master. Oops.
    [DisplayHandler.cpp, HS_ScreenBase.cpp]
2020-02-14 Adding initial partition file (copied from min_spiffs.cxv) Updating readme.txt
    [hardsense_esp_partition.csv]
2020-02-14 Add a few print statmeents in attempt to localize a memory leak
    [DisplayHandler.cpp, HS_GameScreen.cpp]
2020-02-15 Added working button press to open new OTA screen. Going to use this new OTA screen to run the OTA Update user feedback display.
2020-02-16 Adding initial feedback mechanism for updating the display during the ArduinoOTA process.
2020-02-17 Fixed a bug I introduced yesterday that was preventing the screen from updating.
    [DisplayHandler.cpp, HSSerial.cpp, HardSenseESP.ino]
2020-02-17 I think I finally found a fix for the problem where a screen would load, then the numbers displayed would go high out of range. This bug was most noticable when tranisition from the home screen to th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
    [DisplayHandler.cpp]
2020-02-17 Not sure if my last committ/pubh worked. I got some errors, then did some stuff. This commit is just to check that all is well.
    [HardSenseESP.ino]
2020-02-18 New PCB board for HardSense
    [HardSense.kicad_pcb, HardSense.sch]
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2020-02-18 Small change to PCB. Rotated the button header and moved a couple traces.
    [HardSense.kicad_pcb, HardSense.sch]
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2020-02-18 Some minor updates to the pcb
    Moving stuff around as I'm going to create a new KiCad project for the
    NodeMCU-32S board
    [HardSense.kicad_pcb, HardSense.sch]
2020-02-18 Rename the directory
    [HardSense.kicad_pcb, HardSense.sch]
2020-02-19 New KiCad schematic and PCB for ESP32S based system. Updated code with new pin mappings for ESP32S based sytem.
    [HardSense.kicad_pcb, HardSense.sch]
2020-02-19 Add Pin Mapping spreadsheet, step file for new PCB, and a picture of the virtual board.
    [HardSense Pin connections.xls]
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2020-02-20 Updates to PCB board. Changed pin connections from ESP32S to TFT in order to get a better trace line on the PCB.
    [HardSense Pin connections.xls, HardSense.kicad_pcb, HardSense.sch]
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2020-02-21 Fixed the pin mapping to the TFT. I had it wrong and the PCB didn't work. After fixing the pin mapping, all is well.
    [HardSense Pin connections.xls]
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2020-02-26 Adding STL files for the box, and the step file for use in CAD software
    [Back Plate.stl, Base.stl, Display Panel.stl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]
2020-03-11 HardSenseESP now uses INI files to set each screens list of sensors. Sensors ID's are no longer hardcoded and can now be configured easily to use any value. Next step is to update HardSense64 to mana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
    [HS_CPUScreen.h, HS_GameScreen.cpp, HS_GameScreen.h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]
2020-03-11 New User_Setup.h file for use with TFT_eSPI version Fixed text bug on Bluetooth configurator screen as best I can for now.
    [User_Setup.h]
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
